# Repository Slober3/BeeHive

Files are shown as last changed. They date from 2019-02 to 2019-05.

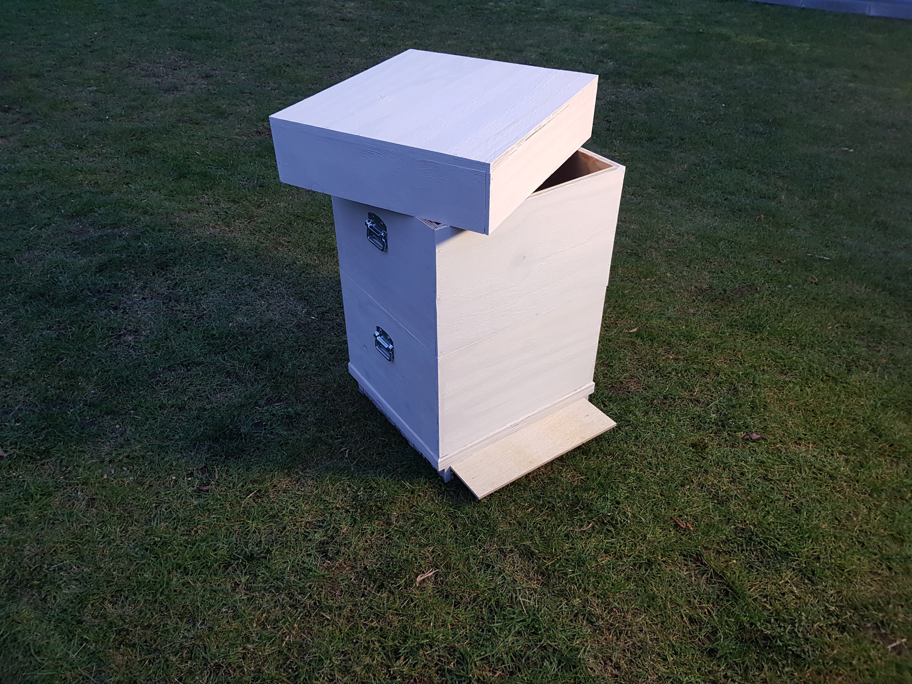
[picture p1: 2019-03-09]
20190309_183631.jpg

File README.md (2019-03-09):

# BeeHive
Beehive Prototype

Open source IOT beehive 

## What is it?
A simple lightweight packet for creating a functional DIY (IOT ready) beehive.

## How does it work?

BEEHIVE:

All the files are publicly available. With these resources you can create your own beehive for the fraction of the cost!

## Is this for anyone?
It's a pre-release and still in the early alpha stage.

## IOT
We are still in the design fase for the hive.
I'ts going to run  through the MQTT protocol and Node-RED

## Contributors
We are still searching brainstormers, users who would like to help and guys who would love to dive into this awesome project.
Manny thanks to the contributers that already are cotributing to this project.

## Contact

1) Email: beehive@7ol.eu

## License
This projects is Licensed under the CC-BY-NC-SA-4.0 license

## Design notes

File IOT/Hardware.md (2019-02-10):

# Controller
The IOT beehive will run on a ESP32 microcontroller platform

## What is it?
ESP32 is a series of low-cost, low-power system on a chip microcontrollers with integrated Wi-Fi and dual-mode Bluetooth. 
The ESP32 series employs a Tensilica Xtensa LX6 microprocessor in both dual-core and single-core variations and includes in-built antenna switches, RF balun, power amplifier, low-noise receive amplifier, filters, and power-management modules.
Source: https://en.wikipedia.org/wiki/ESP32

## Sensor array

We're using a variety of diffrent sensors they include but are not limeted to

1) Barrometric sensor

2) Temperature senor

3) Humidity sensor

4) Volatile Organic Compounds (VOC) sensor

These sensors will be measured by an BME680 Sensor 

## Is this for anyone?
Currently it'll require a moderate knowledge of programming and elektronics.

## API

The API is working! It's still running on fossil fuels and is currently beining updated to run on solar!
```
Formatted JSON Data
[  
   {  
      "id":"1238",
      "temp":"22",
      "gas":"*****",
      "lv":"22",
      "hum":"33"
   }
]
```

## Contributors
We are still searching brainstormers, users who would like to help and guys who would love to dive into this awesome project.
Manny thanks to the contributers that already are cotributing to this project.

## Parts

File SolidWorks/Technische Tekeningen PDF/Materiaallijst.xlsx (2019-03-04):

ITEM NO. | PART NUMBER | DESCRIPTION | QTY.
1 | Bodemplaat met opening voor raster 18mm | Afm. (LBH) 495x457x18 | 1
2 | Balkje lang voor verhoging bodemplaat met raster | Afm. (LBH) 495x12x18 | 1
3 | Balkje kort voor verhoging bodemplaat met raster | Afm. (LBH) 445x12x18 | 2
4 | Bovenplaat van het deksel 18mm dikte | Afm. (LBH) 535x490x18 | 1
5 | Langste zijde dakje buitenkant 18mm dikte | Afm. (LBH) 535x120x18. | 2
6 | Korte zijde dakje buitenkant 18mm dikte | Afm. (LBH) 490x120x18 | 2
7 | Langste zijde dakje binnenkant 18mm dikte | Afm. (LBH) 499x70x18 | 2
8 | Korte zijde dakje binnenkant 18mm dikte | Afm. (LBH) 436x70x18 | 2
9 | Bovenplaat met gat (plexi) | Afm. (LBH) 490x445x(xx) | 1
10 | Lange buitenzijde 18mm dikte | Afm. (LBH) 490x300x18 | 2
11 | Korte buitenzijde 18mm dikte | Afm. (LBH) 427x300x18 | 2
12 | Balkjes 12mm dikte | Afm. (LBH) 454x12x12 | 4
13 | Lange binnenzijde 12mm dikte | Afm. (LBH) 454x277x12 | 2
14 | Binnevlieggat 12mm dikte | Afm. (LBH) 495x25x12 | 1
15 | 30 voetstuk bijenkast bijenkasthouder links rechts 30mm dikte (2) | Afm. (LBH) 457x60x30 | 1
16 | 30 voetstuk bijenkast bijenkasthouder links rechts 30mm dikte | Afm. (LBH) 457x60x30 | 1
17 | luchtplaat afdichting bodem | Afm. (LBH) 455x445x8 | 1
18 | stopplankjes poten | Afm. (LBH) 455x17x12 | 2

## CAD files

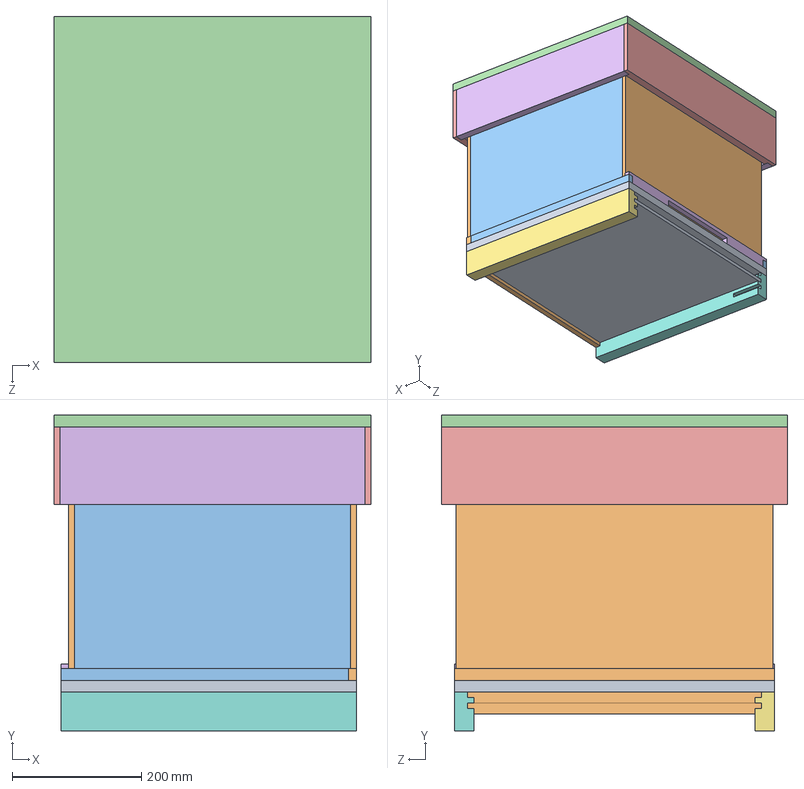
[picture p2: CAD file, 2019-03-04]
SolidWorks/Solidworks assemblys/Bijenkast.SLDASM
490.0 x 488.0 x 535.0 mm
Bodemplaat met opening voor raster 18mm
Balkje lang voor verhoging bodemplaat met raster
Balkje kort voor verhoging bodemplaat met raster x 2
19 Bovenplaat van het deksel 19mm dikte
19 langste zijde dakje buitenkant 19mm dikte x 2
19 korte zijde dakje buitenkant 19mm dikte x 2
19 langste zijde dakje binnenkant 19mm dikte x 2
19 korte zijde dakje binnenkant 19mm dikte x 2
Bovenplaat met gat (plexi)
19 lange buitenzijde 19mm dikte x 2
19 Korte buitenzijde 19mm dikte x 2
12 balkjes 12mm dikte x 4
12 lange binnenzijde 12mm dikte x 2
12 binnevlieggat 12mm dikte
30 voetstuk bijenkast bijenkasthouder links rechts 30mm dikte (2)
30 voetstuk bijenkast bijenkasthouder links rechts 30mm dikte
luchtplaat afdichting bodem
stopplankjes poten x 2

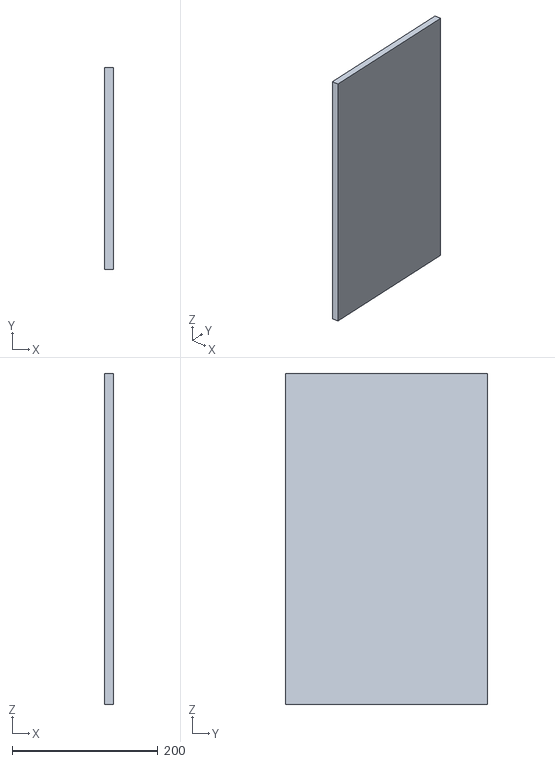
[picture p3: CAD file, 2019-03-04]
STL/Bijenkast - Kast +Dak + Raster bodem + vlieggat Assembly-2 Kast +Dak + Raster bodem Assembly-1 Kast +Dak Assembly-2 Kast Assembly-2 12 lange binnenzijde 12mm dikte-6.STL
12.0 x 277.0 x 454.0

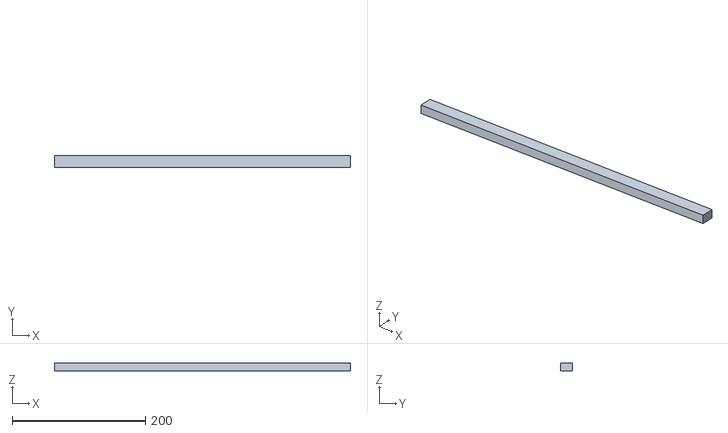
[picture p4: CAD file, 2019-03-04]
STL/Bijenkast - Kast +Dak + Raster bodem + vlieggat Assembly-2 Kast +Dak + Raster bodem Assembly-1 Bodem met raster Assembly-1 Balkje kort voor verhoging bodemplaat met raster-4.STL
445.0 x 18.0 x 12.0

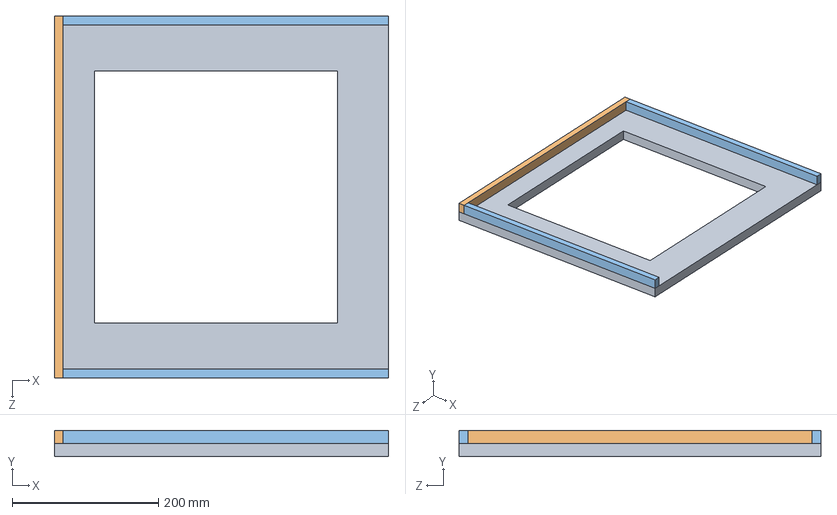
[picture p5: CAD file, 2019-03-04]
SolidWorks/Solidworks assemblys/Bodem met raster Assembly.SLDASM
457.0 x 36.0 x 495.0 mm
Bodemplaat met opening voor raster 18mm
Balkje lang voor verhoging bodemplaat met raster
Balkje kort voor verhoging bodemplaat met raster x 2

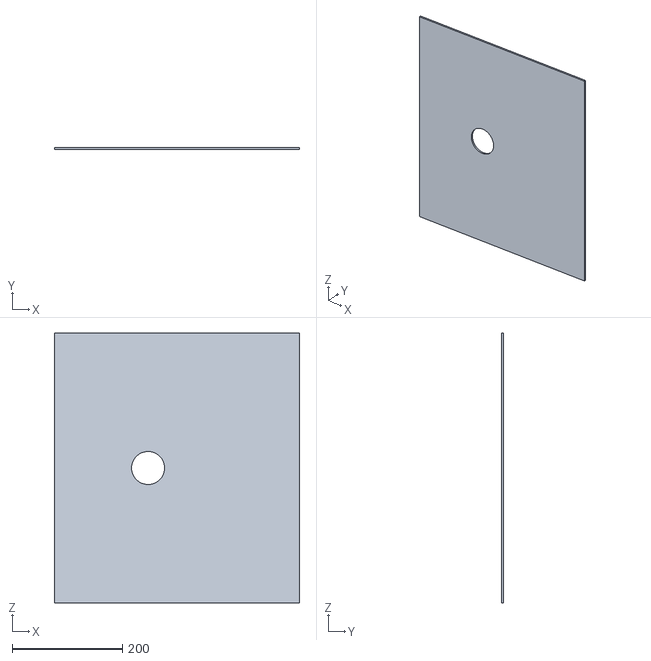
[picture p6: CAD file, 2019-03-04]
STL/Bijenkast - Kast +Dak + Raster bodem + vlieggat Assembly-2 Kast +Dak + Raster bodem Assembly-1 Kast +Dak Assembly-2 Bovenplaat met gat (plexi)-2.STL
445.0 x 4.00 x 490.0

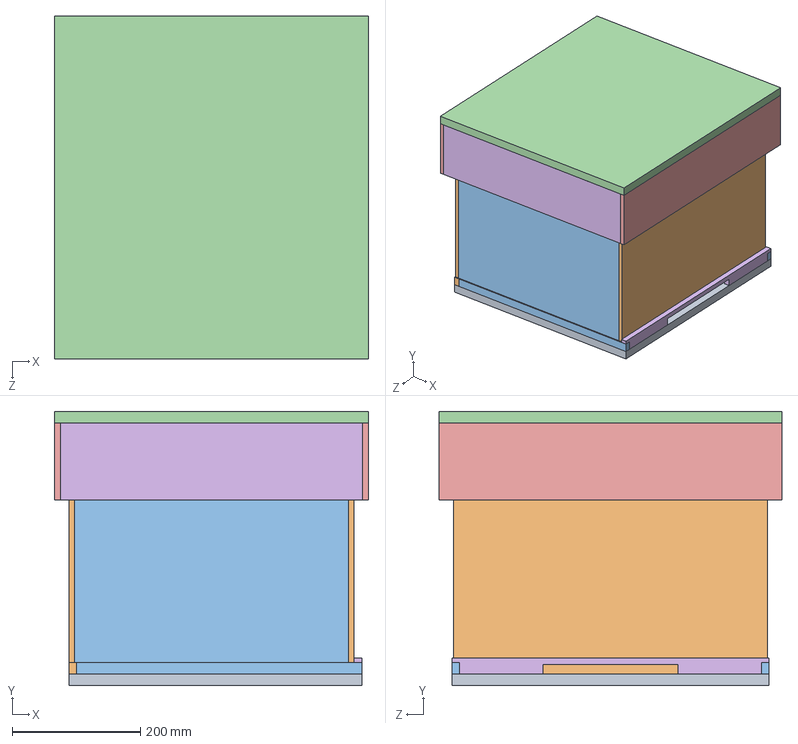
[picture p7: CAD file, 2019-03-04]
SolidWorks/Solidworks assemblys/Kast +Dak + Raster bodem + vlieggat Assembly.SLDASM
490.0 x 428.0 x 535.0 mm
Bodemplaat met opening voor raster 18mm
Balkje lang voor verhoging bodemplaat met raster
Balkje kort voor verhoging bodemplaat met raster x 2
19 Bovenplaat van het deksel 19mm dikte
19 langste zijde dakje buitenkant 19mm dikte x 2
19 korte zijde dakje buitenkant 19mm dikte x 2
19 langste zijde dakje binnenkant 19mm dikte x 2
19 korte zijde dakje binnenkant 19mm dikte x 2
Bovenplaat met gat (plexi)
19 lange buitenzijde 19mm dikte x 2
19 Korte buitenzijde 19mm dikte x 2
12 balkjes 12mm dikte x 4
12 lange binnenzijde 12mm dikte x 2
12 binnevlieggat 12mm dikte

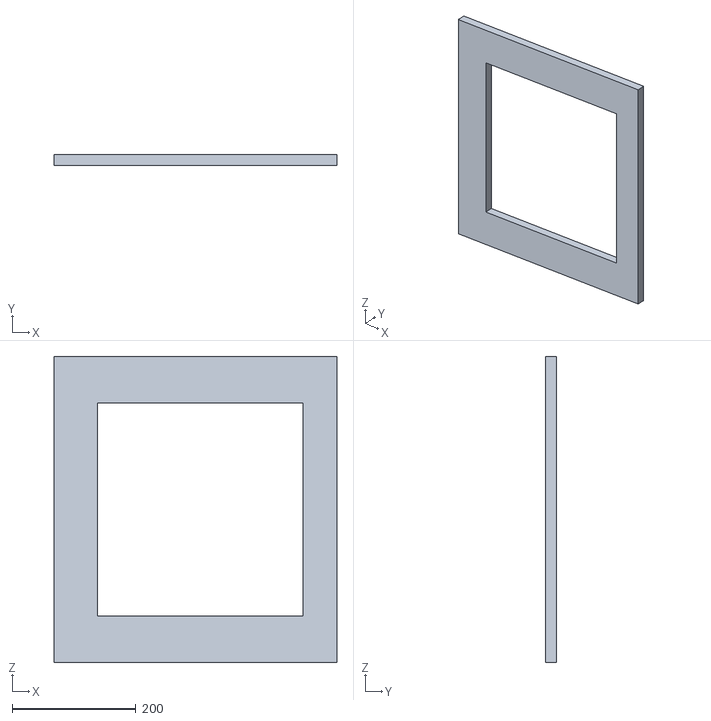
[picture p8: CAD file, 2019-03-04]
STL/Bijenkast - Kast +Dak + Raster bodem + vlieggat Assembly-2 Kast +Dak + Raster bodem Assembly-1 Bodem met raster Assembly-1 Bodemplaat met opening voor raster 18mm-1.STL
457.0 x 18.0 x 495.0

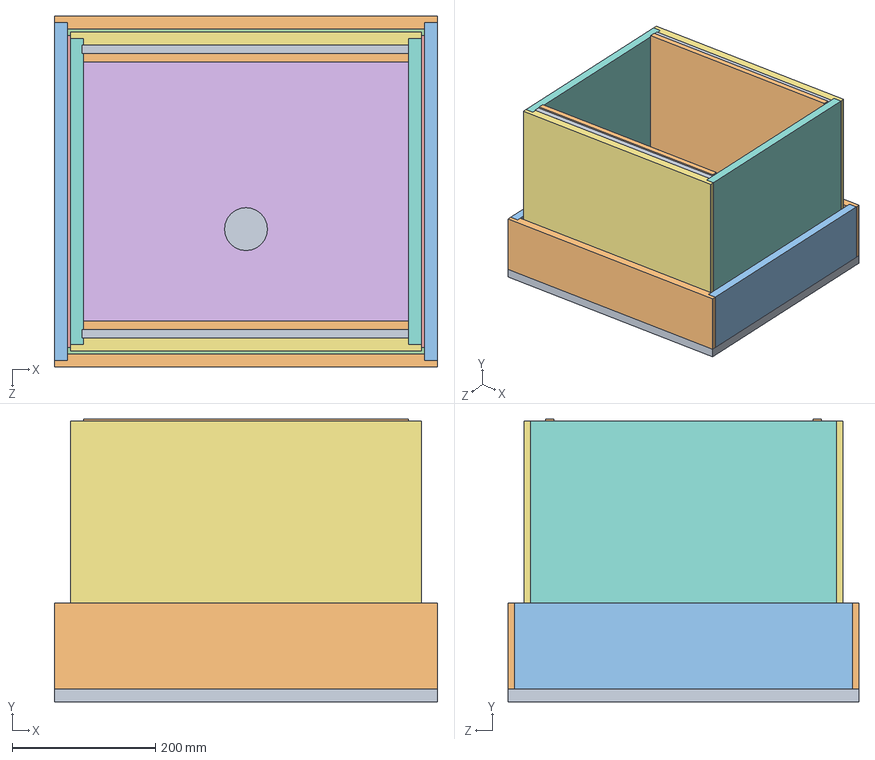
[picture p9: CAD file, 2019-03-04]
SolidWorks/Solidworks assemblys/Kast +Dak Assembly.SLDASM
535.0 x 395.0 x 490.0 mm
19 Bovenplaat van het deksel 19mm dikte
19 langste zijde dakje buitenkant 19mm dikte x 2
19 korte zijde dakje buitenkant 19mm dikte x 2
19 langste zijde dakje binnenkant 19mm dikte x 2
19 korte zijde dakje binnenkant 19mm dikte x 2
Bovenplaat met gat (plexi)
19 lange buitenzijde 19mm dikte x 2
19 Korte buitenzijde 19mm dikte x 2
12 balkjes 12mm dikte x 4
12 lange binnenzijde 12mm dikte x 2

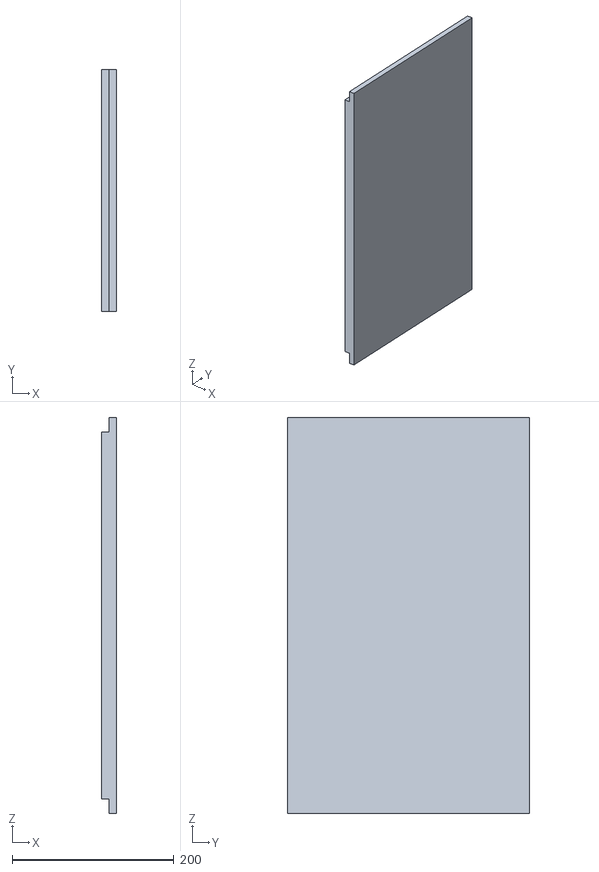
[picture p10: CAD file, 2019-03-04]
STL/Bijenkast - Kast +Dak + Raster bodem + vlieggat Assembly-2 Kast +Dak + Raster bodem Assembly-1 Kast +Dak Assembly-2 Kast Assembly-2 19 lange buitenzijde 19mm dikte-3.STL
18.0 x 300.0 x 490.0

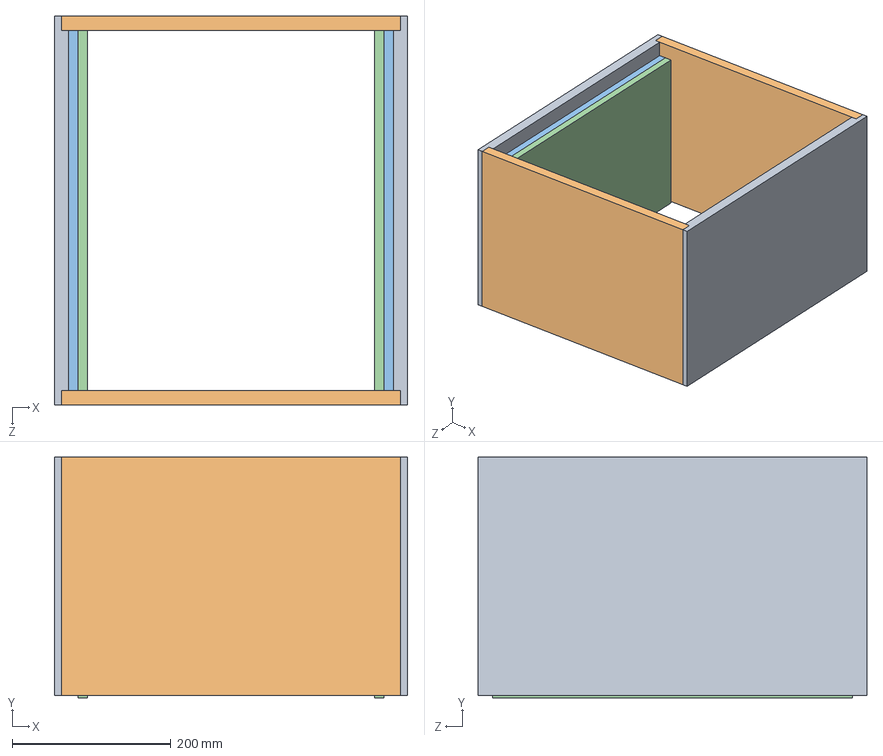
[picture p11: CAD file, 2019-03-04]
SolidWorks/Solidworks assemblys/Kast Assembly.SLDASM
445.0 x 303.0 x 490.0 mm
19 lange buitenzijde 19mm dikte x 2
19 Korte buitenzijde 19mm dikte x 2
12 balkjes 12mm dikte x 4
12 lange binnenzijde 12mm dikte x 2

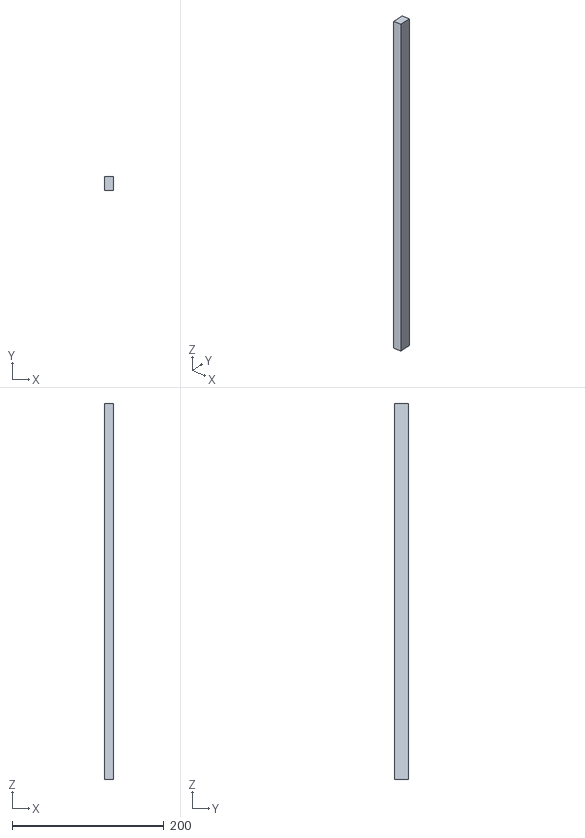
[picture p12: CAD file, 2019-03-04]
STL/Bijenkast - Kast +Dak + Raster bodem + vlieggat Assembly-2 Kast +Dak + Raster bodem Assembly-1 Bodem met raster Assembly-1 Balkje lang voor verhoging bodemplaat met raster-3.STL
12.0 x 18.0 x 495.0

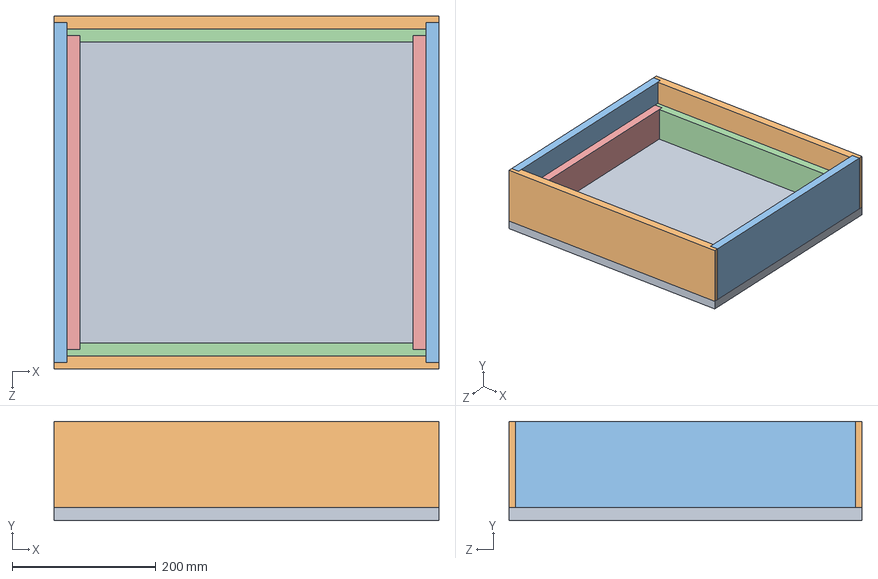
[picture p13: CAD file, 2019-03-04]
SolidWorks/Solidworks assemblys/Dakje Assembly.SLDASM
535.0 x 138.0 x 490.0 mm
19 Bovenplaat van het deksel 19mm dikte
19 langste zijde dakje buitenkant 19mm dikte x 2
19 korte zijde dakje buitenkant 19mm dikte x 2
19 langste zijde dakje binnenkant 19mm dikte x 2
19 korte zijde dakje binnenkant 19mm dikte x 2

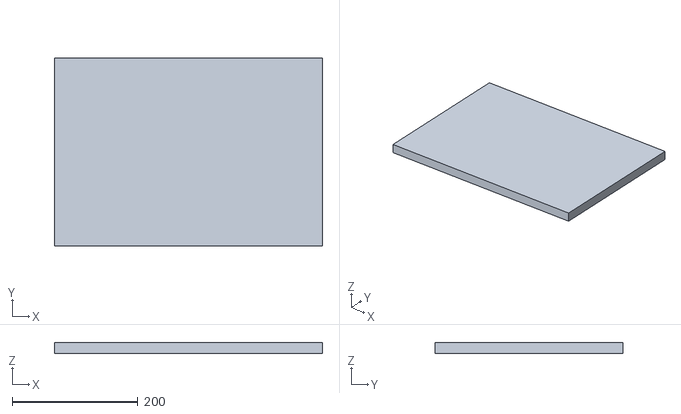
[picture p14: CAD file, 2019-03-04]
STL/Bijenkast - Kast +Dak + Raster bodem + vlieggat Assembly-2 Kast +Dak + Raster bodem Assembly-1 Kast +Dak Assembly-2 Kast Assembly-2 19 Korte buitenzijde 19mm dikte-3.STL
427.0 x 300.0 x 18.0

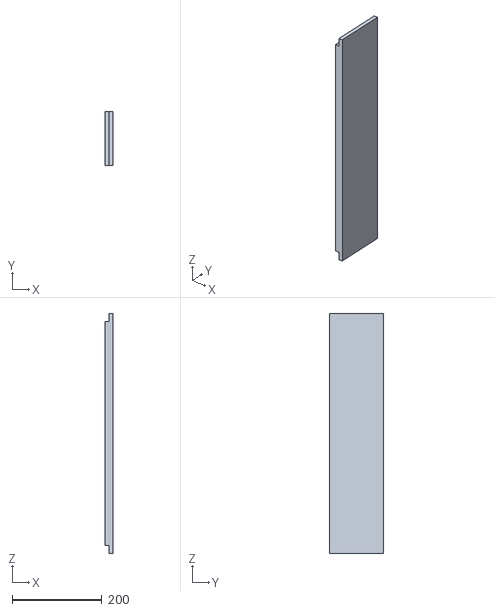
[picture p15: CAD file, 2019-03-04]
STL/Bijenkast - Kast +Dak + Raster bodem + vlieggat Assembly-2 Kast +Dak + Raster bodem Assembly-1 Kast +Dak Assembly-2 Dakje Assembly-1 19 langste zijde dakje buitenkant 19mm dikte-3.STL
18.0 x 120.0 x 535.0

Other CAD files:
SolidWorks/Solidworks assemblys/Kast +Dak + Raster bodem + vlieggat + poten Assembly.SLDASM
SolidWorks/Solidworks assemblys/Kast +Dak + Raster bodem Assembly.SLDASM
STL/Bijenkast - Kast +Dak + Raster bodem + vlieggat Assembly-2 Kast +Dak + Raster bodem Assembly-1 Kast +Dak Assembly-2 Kast Assembly-2 12 lange binnenzijde 12mm dikte-5.STL
STL/Bijenkast - Kast +Dak + Raster bodem + vlieggat Assembly-2 Kast +Dak + Raster bodem Assembly-1 Kast +Dak Assembly-2 Dakje Assembly-1 19 korte zijde dakje buitenkant 19mm dikte-3.STL
STL/Bijenkast - 30 voetstuk bijenkast bijenkasthouder links rechts 30mm dikte (2)-2.STL
STL/Bijenkast - 30 voetstuk bijenkast bijenkasthouder links rechts 30mm dikte-2.STL
STL/Bijenkast - Kast +Dak + Raster bodem + vlieggat Assembly-2 12 binnevlieggat 12mm dikte-1.STL
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

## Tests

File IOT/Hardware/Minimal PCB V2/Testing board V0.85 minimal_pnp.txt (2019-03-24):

*Pick And Place List
*Company=
*Author=
*eMail=
*
*Project=Testing board V0.85 minimal
*Date=13:51:05
*CreatedBy=Fritzing 0.9.3b.04.19.5c895d327c44a3114e5fcc9d8260daf0cbb52806
*
*
*Coordinates in mm, always center of component
*Origin 0/0=Lower left corner of PCB
*Rotation in degree (0-360, math. pos.)
*
*No;Value;Package;X;Y;Rotation;Side;Name
1;;molex-1x6-ra;45.3283;-15.377;0;Bottom;JP3
2;;;30.3478;-32.3251;0;Bottom;Onderdeel2
3;;;89.7783;-88.2051;0;Bottom;Hole6
4;;THT;17.7413;-11.4972;-90;Bottom;J8
5;;molex-1x6-ra;35.1683;-33.157;0;Bottom;JP1
6;;battery-18650-kit;43.0123;-57.6766;180;Bottom;BAT2
7;;THT;89.2703;-25.6222;0;Bottom;J11
8;;molex-1x6-ra;35.1683;-30.617;0;Bottom;JP2
9;;THT;89.2703;-15.4622;0;Bottom;J10
10;;battery-18650-kit;43.0123;-80.5366;180;Bottom;BAT1
11;;THT;89.2703;-5.30219;0;Bottom;J9
12;;;69.43;-10.6637;180;Bottom;Onderdeel3
13;;;64.3783;-31.6901;180;Bottom;Onderdeel1
14;;;5.95826;-4.38515;0;Bottom;Hole5

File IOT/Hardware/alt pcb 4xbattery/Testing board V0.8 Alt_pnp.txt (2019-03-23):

*Pick And Place List
*Company=
*Author=
*eMail=
*
*Project=Testing board V0.8 Alt
*Date=20:23:50
*CreatedBy=Fritzing 0.9.3b.04.19.5c895d327c44a3114e5fcc9d8260daf0cbb52806
*
*
*Coordinates in mm, always center of component
*Origin 0/0=Lower left corner of PCB
*Rotation in degree (0-360, math. pos.)
*
*No;Value;Package;X;Y;Rotation;Side;Name
1;;THT;28.6901;-62.2553;0;Bottom;J13
2;;;13.9581;-106.733;0;Bottom;Onderdeel1
3;;;21.5781;-40.0584;0;Bottom;Hole5
4;;battery-18650-kit;78.1647;-65.5234;0;Bottom;BAT3
5;;;115.558;-7.03843;0;Bottom;Hole6
6;;THT;28.6901;-92.7354;0;Bottom;J7
7;;battery-18650-kit;78.1647;-106.164;0;Bottom;BAT1
8;;battery-18650-kit;78.1647;-85.8435;0;Bottom;BAT2
9;;;13.9581;-111.178;0;Bottom;Hole4
10;;battery-18650-kit;78.1647;-45.2034;0;Bottom;BAT4
11;;THT;5.83015;-36.8553;0;Bottom;J5
12;;THT;28.6901;-82.5753;0;Bottom;J8
13;;2x10_lock;22.9751;-18.4684;90;Bottom;JP1
14;;;6.33813;-7.03843;0;Bottom;Hole1
15;;THT;5.83015;-47.0153;0;Bottom;J6
16;;;73.3884;-17.1984;0;Bottom;Onderdeel2
17;;THT;5.83015;-26.6953;0;Bottom;J20
18;;THT;28.6901;-72.4153;0;Bottom;J9
19;;;24.1464;-41.2573;0;Bottom;Onderdeel3

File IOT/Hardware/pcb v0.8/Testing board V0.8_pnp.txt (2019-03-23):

*Pick And Place List
*Company=
*Author=
*eMail=
*
*Project=Testing board V0.8
*Date=20:27:05
*CreatedBy=Fritzing 0.9.3b.04.19.5c895d327c44a3114e5fcc9d8260daf0cbb52806
*
*
*Coordinates in mm, always center of component
*Origin 0/0=Lower left corner of PCB
*Rotation in degree (0-360, math. pos.)
*
*No;Value;Package;X;Y;Rotation;Side;Name
1;;;75.9284;-27.3584;0;Bottom;Onderdeel2
2;;;21.5781;-45.1384;0;Bottom;Hole5
3;;;6.33813;-7.03843;0;Bottom;Hole1
4;;THT;36.1552;-22.7865;90;Bottom;J25
5;;THT;15.9901;-29.2353;0;Bottom;J20
6;;THT;8.37015;-38.4355;0;Bottom;J5
7;;battery-18650-kit;76.4121;-85.8269;0;Bottom;BAT2
8;;THT;8.37015;-48.5955;0;Bottom;J6
9;;;26.6864;-43.7973;0;Bottom;Onderdeel3
10;;THT;28.6901;-82.5753;0;Bottom;J8
11;;;115.558;-7.03843;0;Bottom;Hole6
12;;;13.9581;-111.178;0;Bottom;Hole4
13;;THT;28.6901;-72.4153;0;Bottom;J9
14;;THT;36.1551;-15.1664;90;Bottom;J26
15;;THT;28.6901;-92.7354;0;Bottom;J7
16;;THT;33.6152;-63.4265;90;Bottom;J13
17;;THT;36.1552;-30.4065;90;Bottom;J24
18;;battery-18650-kit;76.4121;-65.5068;0;Bottom;BAT3
19;;;13.9581;-106.733;0;Bottom;Onderdeel1
20;;THT;8.37015;-79.0755;0;Bottom;J1
21;;battery-18650-kit;76.4121;-106.147;0;Bottom;BAT1
22;;THT;8.37015;-89.2354;0;Bottom;J2

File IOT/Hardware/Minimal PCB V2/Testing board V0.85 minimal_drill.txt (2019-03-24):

; NON-PLATED HOLES START AT T1
; THROUGH (PLATED) HOLES START AT T100
M48
INCH
T1C0.049194
T2C0.126000
T3C0.165354
T100C0.073000
T101C0.031496
T102C0.031833
T103C0.040000
T104C0.098425
T105C0.035433
T106C0.086614
T107C0.039370
%
T1
X022345Y002670
T2
X006073Y031727
X027970Y022728
X006073Y022728
X027970Y031727
T3
X035345Y034726
X002345Y001726
T100
X002655Y031732
X031345Y031726
X002655Y022733
X031345Y022726
T101
X002950Y014025
X002950Y011427
T102
X022345Y005670
X022345Y004670
X032470Y001642
X032470Y005642
X032470Y002642
X032470Y003642
X032470Y004642
X022345Y003670
X032470Y006642
T103
X006345Y004726
X017345Y004726
X014345Y010726
X015345Y011726
X013345Y011726
X035345Y010726
X013345Y010726
X018345Y004726
X016345Y011726
X011345Y010726
X012345Y011726
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

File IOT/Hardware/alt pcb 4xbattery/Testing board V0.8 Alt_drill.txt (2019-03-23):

; NON-PLATED HOLES START AT T1
; THROUGH (PLATED) HOLES START AT T100
M48
INCH
T1C0.126000
T2C0.049194
T3C0.165354
T100C0.031496
T101C0.040000
T102C0.086614
T103C0.039370
T104C0.035433
T105C0.073000
T106C0.031833
T107C0.098425
%
T1
X041810Y025776
X041810Y017776
X019912Y033776
X019912Y025776
X019912Y017776
X019912Y041776
X041810Y041776
X041810Y033776
T2
X014495Y017771
T3
X005495Y043771
X008495Y015771
X045495Y002770
X002495Y002770
T100
X037890Y005471
X037890Y008070
T101
X008495Y002770
X011495Y035771
X009495Y008771
X009495Y002770
X008495Y004770
X011495Y027771
X009495Y010771
X011495Y023771
X009595Y005770
X008595Y005770
X002495Y009771
X009595Y007770
X008495Y008771
X008595Y009771
X002495Y015148
X011495Y031771
X009495Y006770
X009595Y003770
X009595Y011771
X011495Y037149
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

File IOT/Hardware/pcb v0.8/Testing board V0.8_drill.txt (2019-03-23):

; NON-PLATED HOLES START AT T1
; THROUGH (PLATED) HOLES START AT T100
M48
INCH
T1C0.049194
T2C0.165354
T3C0.126000
T100C0.031496
T101C0.040000
T102C0.086614
T103C0.039370
T104C0.035433
T105C0.073000
T106C0.031833
T107C0.098425
%
T1
X015495Y018771
T2
X005495Y043771
X008495Y017771
X045495Y002770
X002495Y002770
T3
X041120Y041769
X019222Y041769
X041120Y033769
X019222Y025769
X041120Y025769
X019222Y033769
T100
X038890Y009471
X038890Y012070
T101
X014873Y011771
X011495Y035771
X011495Y027771
X013495Y005770
X003495Y018393
X013495Y011771
X013873Y024771
X003495Y015771
X003495Y031771
X003495Y014393
X003495Y019771
X006495Y012148
X011495Y031771
X006495Y010771
X014873Y005770
X003495Y034393
X011495Y037149
X013495Y008771
X003495Y030393
X003495Y035771
X011495Y033148
X014873Y008771
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

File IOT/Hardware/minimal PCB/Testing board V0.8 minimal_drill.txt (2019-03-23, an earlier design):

; NON-PLATED HOLES START AT T1
; THROUGH (PLATED) HOLES START AT T100
M48
INCH
T1C0.126000
T2C0.049194
T3C0.165354
T100C0.039370
T101C0.035433
T102C0.098425
T103C0.040000
T104C0.073000
T105C0.086614
T106C0.031496
T107C0.031833
%
T1
X027810Y028037
X005912Y019037
X005912Y028037
X027810Y019037
T2
X011370Y024963
T3
X031495Y001991
X002495Y001991
T100
X025495Y007991
X023495Y007991
X022495Y007991
X026495Y007991
X024495Y007991
X028495Y007991
X027495Y007991
T101
X011533Y013007
X004533Y005007
X015533Y005007
X012533Y013007
X014533Y005007
X010533Y005007
X007533Y005007
X002035Y010424
X006533Y005007
X011533Y005007
X012533Y005007
X016533Y013007
X008533Y005007
X018533Y005007
X017533Y005007
X014533Y013007
X007533Y013007
X013533Y005007
X009533Y013007
X015533Y013007
X017533Y013007
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

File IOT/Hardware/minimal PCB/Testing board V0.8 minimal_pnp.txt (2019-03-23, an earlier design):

*Pick And Place List
*Company=
*Author=
*eMail=
*
*Project=Testing board V0.8 minimal
*Date=21:03:38
*CreatedBy=Fritzing 0.9.3b.04.19.5c895d327c44a3114e5fcc9d8260daf0cbb52806
*
*
*Coordinates in mm, always center of component
*Origin 0/0=Lower left corner of PCB
*Rotation in degree (0-360, math. pos.)
*
*No;Value;Package;X;Y;Rotation;Side;Name
1;;THT;61.7101;-50.1154;0;Bottom;J11
2;;battery-18650-kit;42.6047;-71.1635;180;Bottom;BAT1
3;;;30.8251;-22.8782;0;Bottom;Onderdeel2
4;;;64.7581;-26.0134;0;Bottom;Onderdeel1
5;;;41.5524;-59.5268;0;Bottom;Onderdeel3
6;;molex-1x6-ra;35.5481;-26.2103;0;Bottom;JP1
7;;;79.9981;-5.05843;0;Bottom;Hole6
8;;THT;19.7011;-7.09053;-90;Bottom;J8
9;;THT;61.7101;-70.4354;0;Bottom;J9
10;;battery-18650-kit;42.6047;-48.3035;180;Bottom;BAT2
11;;THT;61.7101;-60.2754;0;Bottom;J10
12;;;6.33813;-5.05843;0;Bottom;Hole5

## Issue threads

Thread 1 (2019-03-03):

Dak bijenkast te groot

Slober3, 2019-03-03:
Verkeerde afmetingen van het dak.
Dit kan verholpen worden door de bovenplaat van het dak in te korten.
Dit zal verholpen worden in een toekomstige update.

Er zal tevens geopteerd worden om de zijpanelen van het dak te verzinken zoals ook gebeurd bij de buitenpanelen.

Slober3, 2019-03-03:
Update:

Dakje is gereviseerd probleem zou opgelost moeten zijn.

Closed 2019-03-03.

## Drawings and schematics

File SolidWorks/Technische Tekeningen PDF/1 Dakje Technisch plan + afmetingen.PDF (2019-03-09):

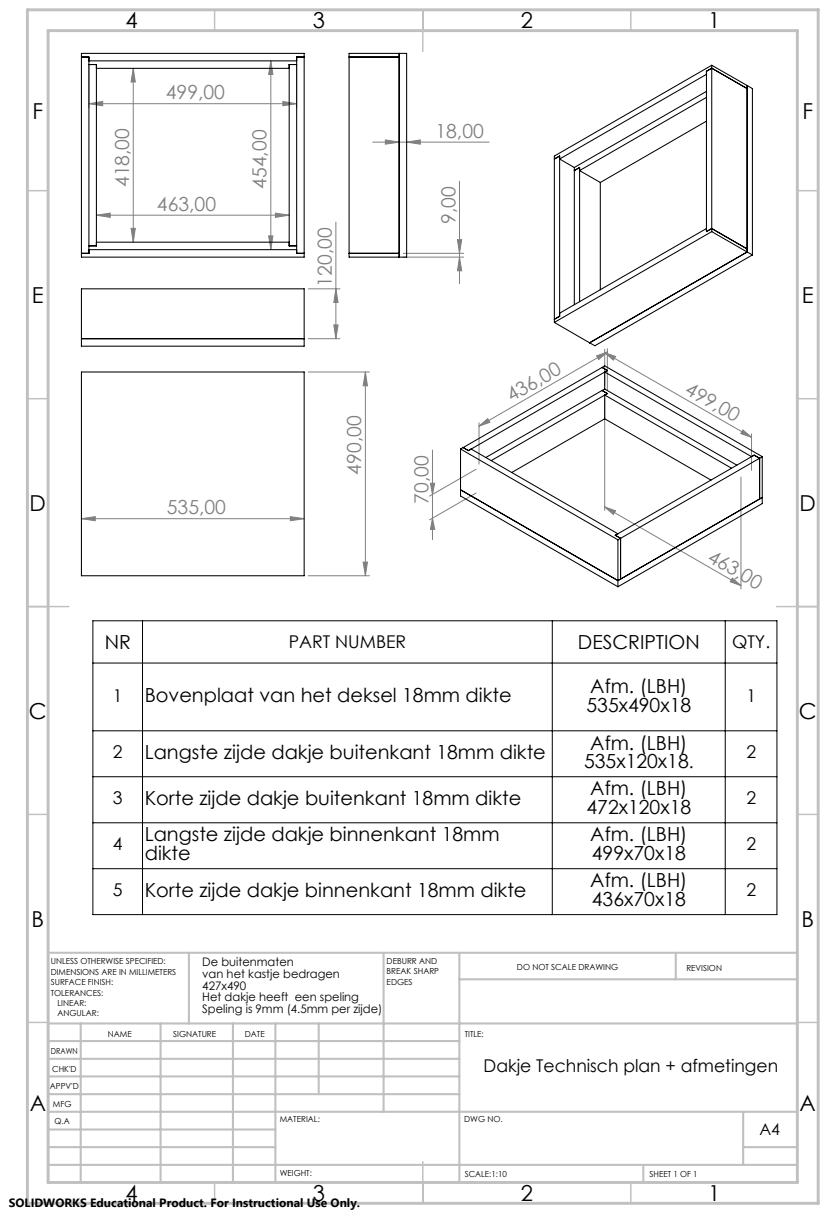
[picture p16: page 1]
DEBURR AND BREAK SHARP; DO NOT SCALE DRAWING; REVISION; SCALE:1:10; SHEET 1 OF 1

NR | PART NUMBER | DESCRIPTION | QTY.
1 | Bovenplaat van het deksel 18mm dikte | Afm. (LBH) 535x490x18 | 1

2 | Langste zijde dakje buitenkant 18mm dikte | Afm. (LBH) 535x120x18. | 2
3 | Korte zijde dakje buitenkant 18mm dikte | Afm. (LBH) 472x120x18 | 2
4 | Langste zijde dakje binnenkant 18mm dikte | Afm. (LBH) 499x70x18 | 2
5 | Korte zijde dakje binnenkant 18mm dikte | Afm. (LBH) 436x70x18 | 2

UNLESS OTHERWISE SPECIFIED:
DIMENSIONS ARE IN MILLIMETERS
SURFACE FINISH:
TOLERANCES:
LINEAR:
ANGULAR:

De buitenmaten
van het kastje bedragen
Het dakje heeft een speling
Speling is 9mm (4.5mm per zijde)

NAME | SIGNATURE | DATE | | | | TITLE: Dakje Technisch plan + afmetingen

DRAWN
CHK'D
APPV'D
MFG
Q.A | | | | MATERIAL: | DWG NO. | A4

SOLIDWORKS Educational Product. For Instructional Use Only.

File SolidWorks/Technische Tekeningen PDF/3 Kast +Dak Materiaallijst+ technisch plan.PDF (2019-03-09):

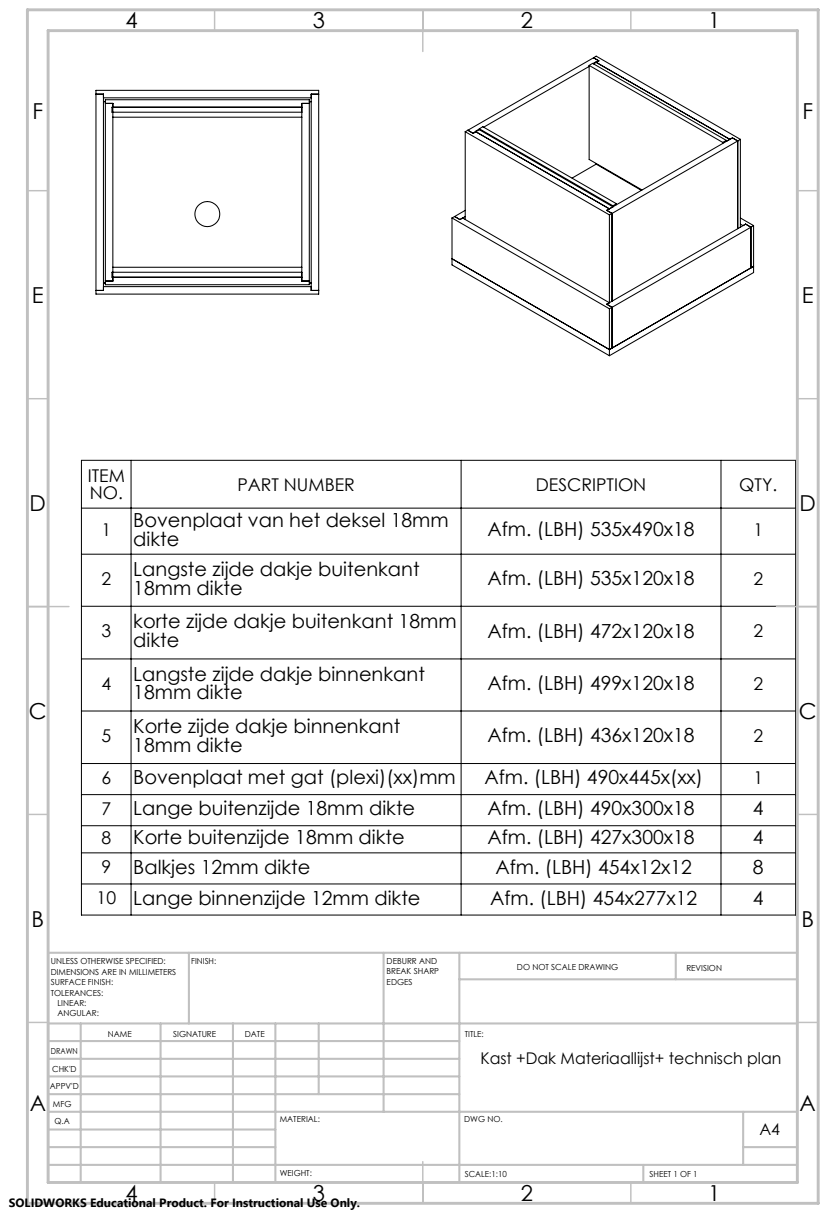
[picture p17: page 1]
FINISH:; DEBURR AND; BREAK SHARP; DO NOT SCALE DRAWING; REVISION; SCALE:1:10; SHEET 1 OF 1

ITEM NO. | PART NUMBER | DESCRIPTION | QTY.
1 | Bovenplaat van het deksel 18mm dikte | Afm. (LBH) 535x490x18 | 1
2 | Langste zijde dakje buitenkant 18mm dikte | Afm. (LBH) 535x120x18 | 2

3 | korte zijde dakje buitenkant 18mm dikte | Afm. (LBH) 472x120x18 | 2

4 | Langste zijde dakje binnenkant 18mm dikte | Afm. (LBH) 499x120x18 | 2

5 | Korte zijde dakje binnenkant 18mm dikte | Afm. (LBH) 436x120x18 | 2

6 | Bovenplaat met gat (plexi)(xx)mm | Afm. (LBH) 490x445x(xx) | 1
7 | Lange buitenzijde 18mm dikte | Afm. (LBH) 490x300x18 | 4
8 | Korte buitenzijde 18mm dikte | Afm. (LBH) 427x300x18 | 4
9 | Balkjes 12mm dikte | Afm. (LBH) 454x12x12 | 8
10 | Lange binnenzijde 12mm dikte | Afm. (LBH) 454x277x12 | 4

UNLESS OTHERWISE SPECIFIED:
DIMENSIONS ARE IN MILLIMETERS
SURFACE FINISH:
TOLERANCES:
LINEAR:
ANGULAR:

NAME | SIGNATURE | DATE | | | | TITLE: Kast +Dak Materiaallijst+ technisch plan

DRAWN
CHK'D
APPV'D
MFG
Q.A | | | | MATERIAL: | DWG NO. | A4

SOLIDWORKS Educational Product. For Instructional Use Only.

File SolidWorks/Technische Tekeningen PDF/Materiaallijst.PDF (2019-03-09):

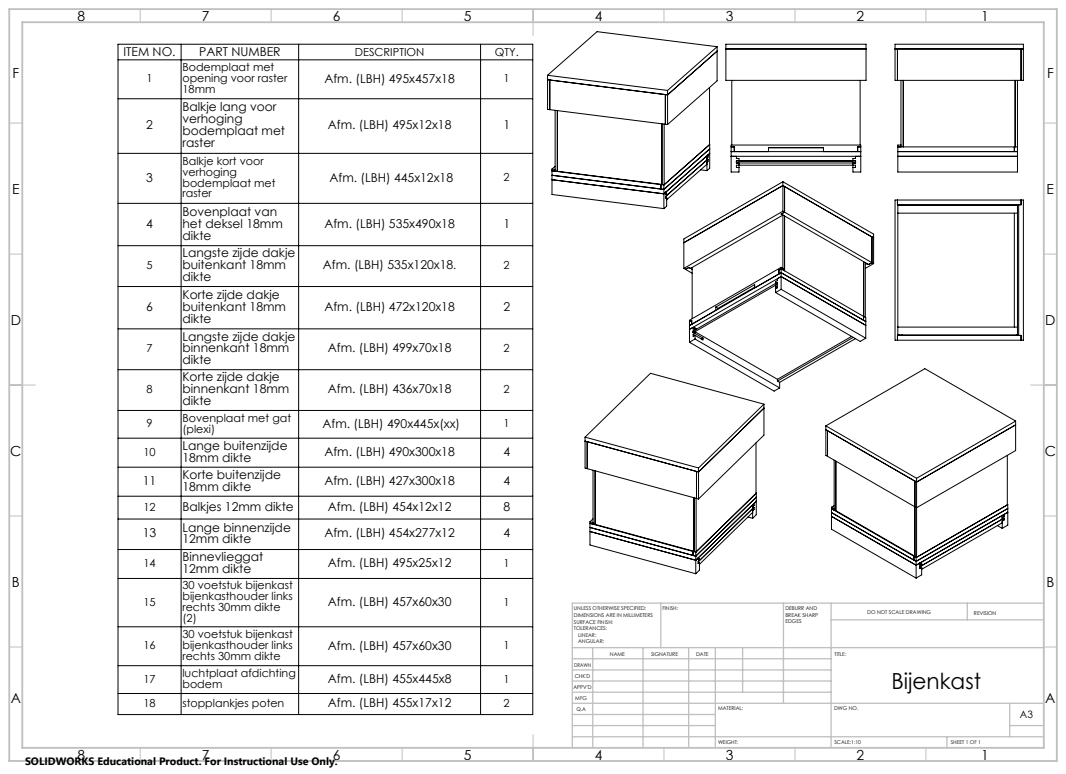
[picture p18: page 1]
stopplankjes poten; Afm. (LBH) 455x17x12; FINISH:; DEBURR AND; BREAK SHARP; DO NOT SCALE DRAWING; REVISION; SCALE:1:10; SHEET 1 OF 1

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

2 | Balkje lang voor verhoging bodemplaat met raster | Afm. (LBH) 495x12x18 | 1

3 | Balkje kort voor verhoging bodemplaat met raster | Afm. (LBH) 445x12x18 | 2

4 | Bovenplaat van het deksel 18mm dikte | Afm. (LBH) 535x490x18 | 1

5 | Langste zijde dakje buitenkant 18mm dikte | Afm. (LBH) 535x120x18. | 2

6 | Korte zijde dakje buitenkant 18mm dikte | Afm. (LBH) 472x120x18 | 2

7 | Langste zijde dakje binnenkant 18mm dikte | Afm. (LBH) 499x70x18 | 2

8 | Korte zijde dakje binnenkant 18mm dikte | Afm. (LBH) 436x70x18 | 2

9 | Bovenplaat met gat (plexi) | Afm. (LBH) 490x445x(xx) | 1
10 | Lange buitenzijde 18mm dikte | Afm. (LBH) 490x300x18 | 4
11 | Korte buitenzijde 18mm dikte | Afm. (LBH) 427x300x18 | 4

12 | Balkjes 12mm dikte | Afm. (LBH) 454x12x12 | 8
13 | Lange binnenzijde 12mm dikte | Afm. (LBH) 454x277x12 | 4
14 | Binnevlieggat 12mm dikte | Afm. (LBH) 495x25x12 | 1

15 | 30 voetstuk bijenkast bijenkasthouder links rechts 30mm dikte (2) | Afm. (LBH) 457x60x30 | 1

UNLESS OTHERWISE SPECIFIED:
DIMENSIONS ARE IN MILLIMETERS
SURFACE FINISH:
TOLERANCES:
LINEAR:
ANGULAR:

16 | 30 voetstuk bijenkast bijenkasthouder links rechts 30mm dikte | Afm. (LBH) 457x60x30 | 1

NAME | SIGNATURE | DATE | | | | TITLE: Bijenkast

DRAWN
CHK'D
APPV'D
MFG
Q.A | | | | MATERIAL: | DWG NO. | A3

17 | luchtplaat afdichting bodem | Afm. (LBH) 455x445x8 | 1

SOLIDWORKS Educational Product. For Instructional Use Only.

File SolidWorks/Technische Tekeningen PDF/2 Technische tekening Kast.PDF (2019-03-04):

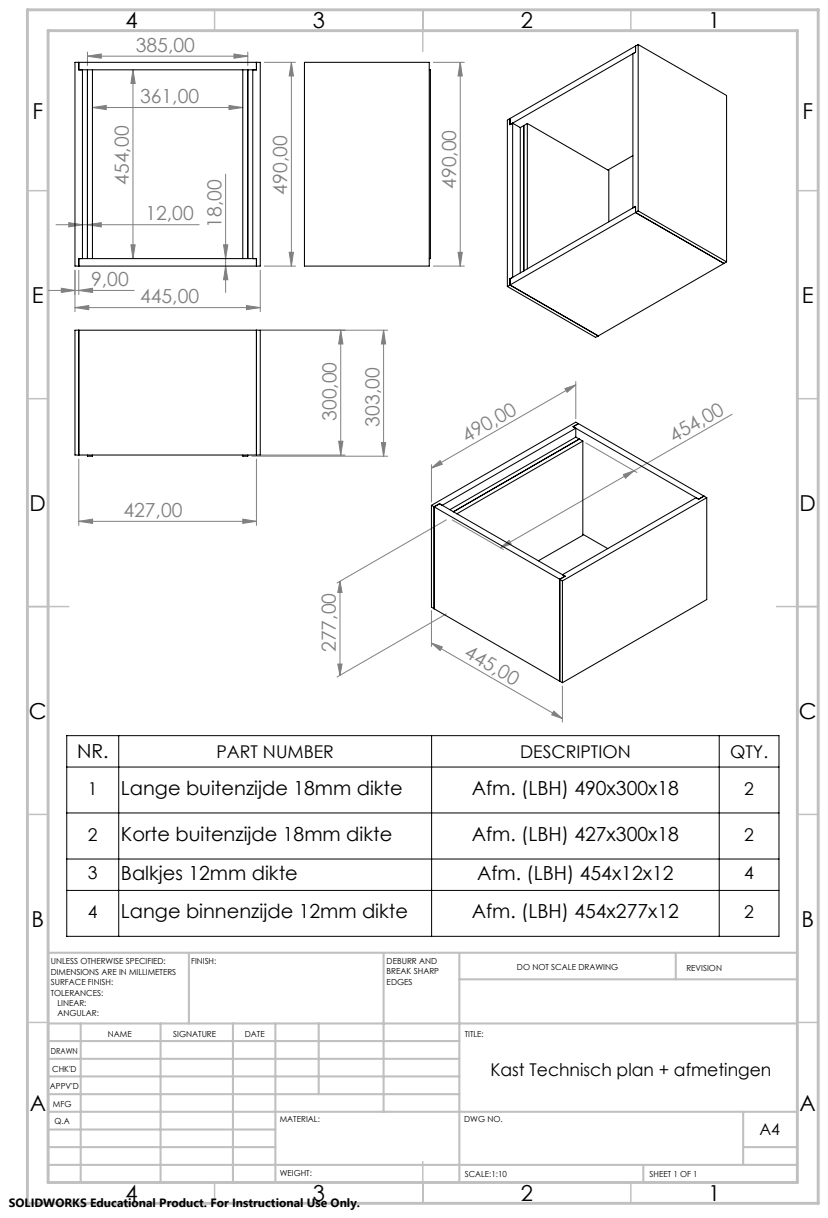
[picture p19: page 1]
Korte buitenzijde 18mm dikte; Afm. (LBH) 427x300x18; FINISH:; DEBURR AND; BREAK SHARP; DO NOT SCALE DRAWING; REVISION; SCALE:1:10; SHEET 1 OF 1

NR. | PART NUMBER | DESCRIPTION | QTY.
1 | Lange buitenzijde 18mm dikte | Afm. (LBH) 490x300x18 | 2

3 | Balkjes 12mm dikte | Afm. (LBH) 454x12x12 | 4
4 | Lange binnenzijde 12mm dikte | Afm. (LBH) 454x277x12 | 2

UNLESS OTHERWISE SPECIFIED:
DIMENSIONS ARE IN MILLIMETERS
SURFACE FINISH:
TOLERANCES:
LINEAR:
ANGULAR:

NAME | SIGNATURE | DATE | | | | TITLE: Kast Technisch plan + afmetingen

DRAWN
CHK'D
APPV'D
MFG
Q.A | | | | MATERIAL: | DWG NO. | A4

SOLIDWORKS Educational Product. For Instructional Use Only.

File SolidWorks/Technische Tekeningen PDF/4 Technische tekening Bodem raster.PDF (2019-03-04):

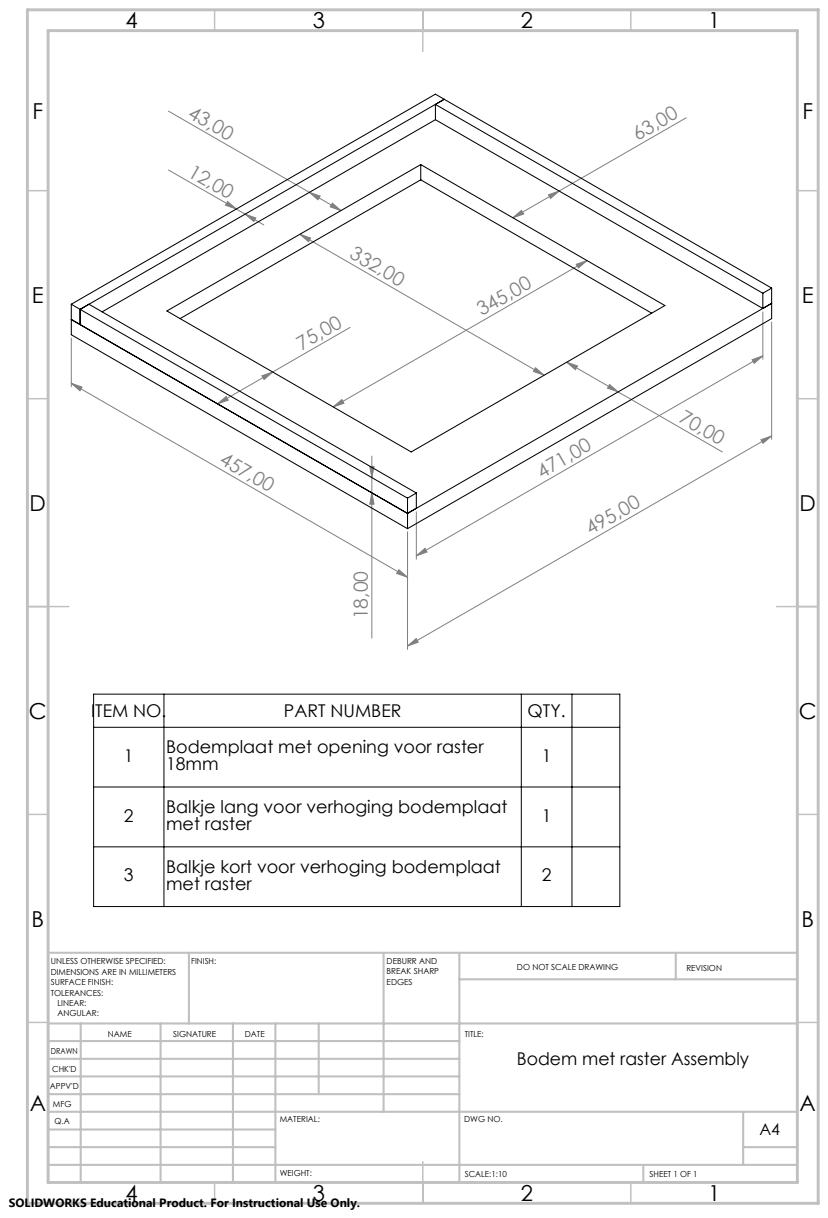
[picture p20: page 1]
ITEM NO.; PART NUMBER; QTY.; FINISH:; DEBURR AND; BREAK SHARP; DO NOT SCALE DRAWING; REVISION; SCALE:1:10; SHEET 1 OF 1

1 | Bodemplaat met opening voor raster 18mm | 1

2 | Balkje lang voor verhoging bodemplaat met raster | 1

3 | Balkje kort voor verhoging bodemplaat met raster | 2

UNLESS OTHERWISE SPECIFIED:
DIMENSIONS ARE IN MILLIMETERS
SURFACE FINISH:
TOLERANCES:
LINEAR:
ANGULAR:

NAME | SIGNATURE | DATE | | | | TITLE: Bodem met raster Assembly

DRAWN
CHK'D
APPV'D
MFG
Q.A | | | | MATERIAL: | DWG NO. | A4

SOLIDWORKS Educational Product. For Instructional Use Only.

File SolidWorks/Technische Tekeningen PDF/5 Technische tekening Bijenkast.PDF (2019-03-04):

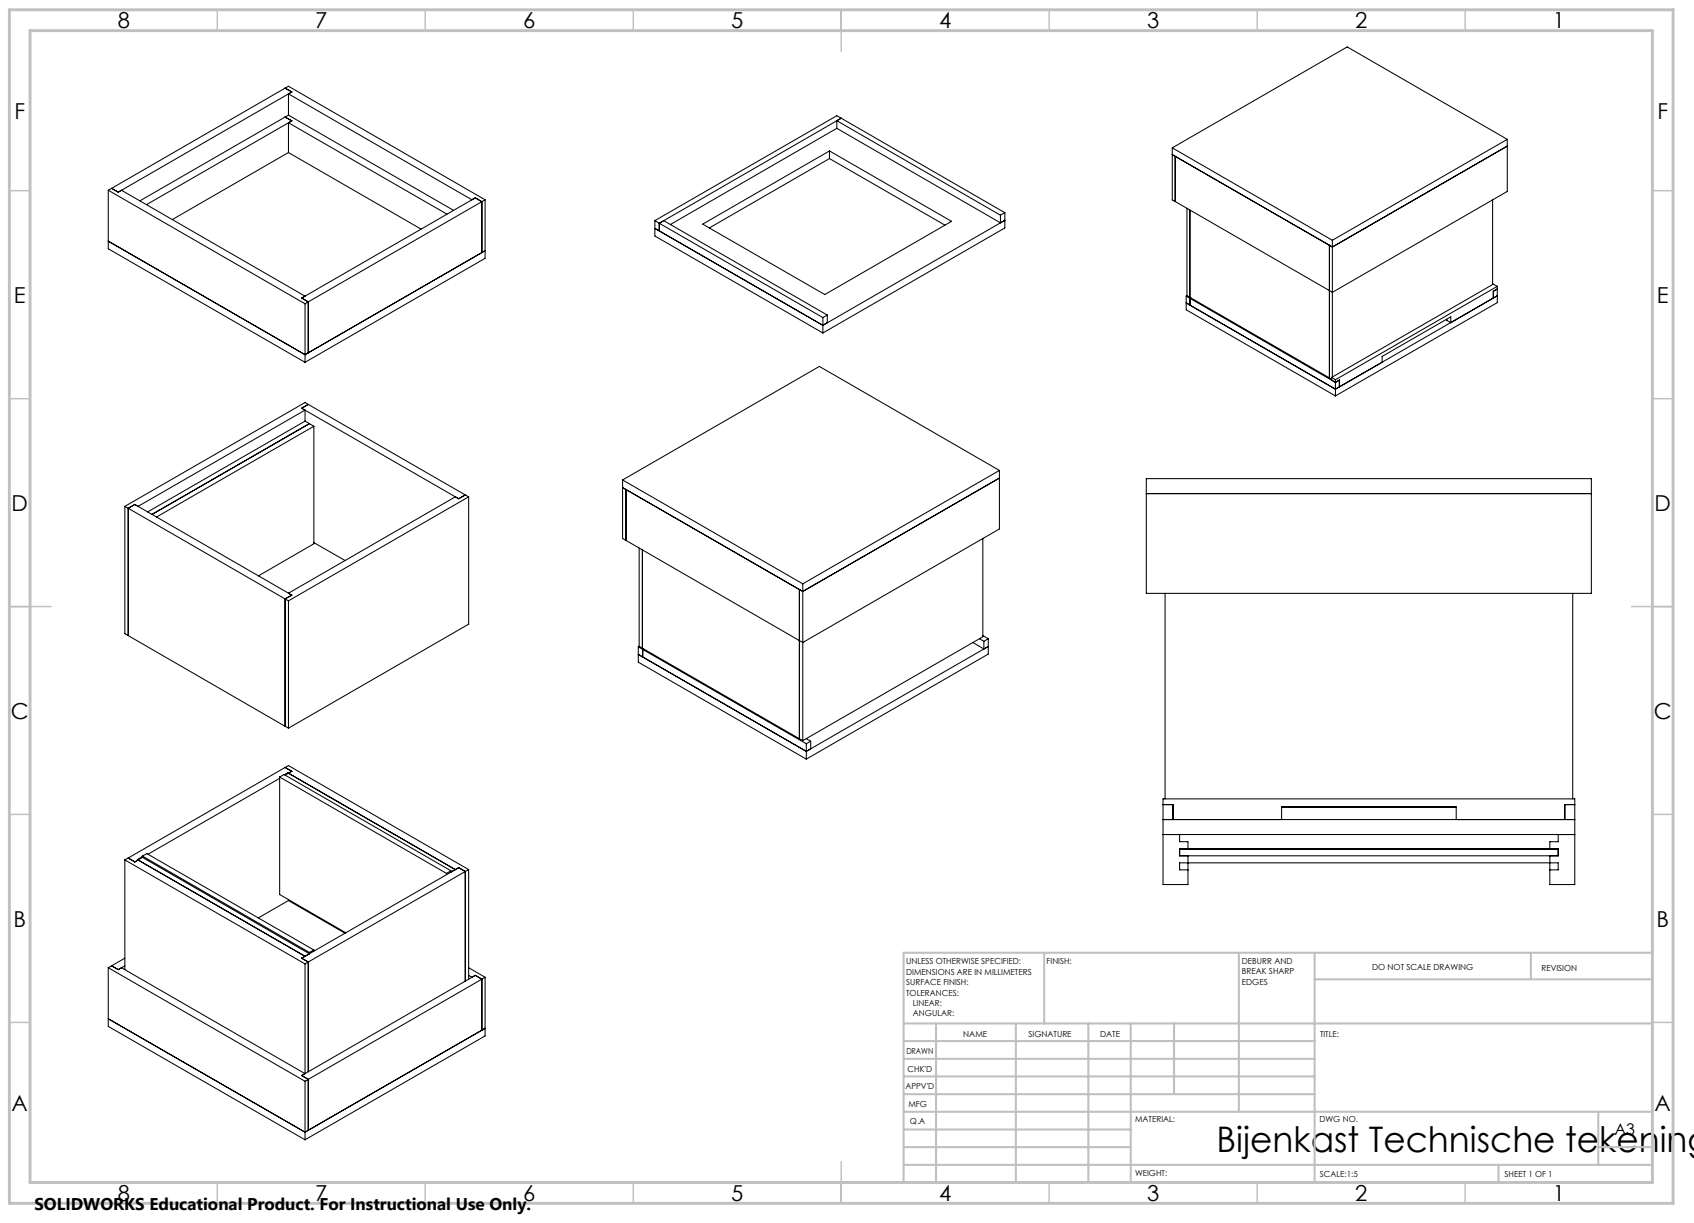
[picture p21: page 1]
FINISH:; DEBURR AND; BREAK SHARP; DO NOT SCALE DRAWING; REVISION; SCALE:1:5; SHEET 1 OF 1

UNLESS OTHERWISE SPECIFIED:
DIMENSIONS ARE IN MILLIMETERS
SURFACE FINISH:
TOLERANCES:
LINEAR:
ANGULAR:

NAME | SIGNATURE | DATE | | | | TITLE:

DRAWN
CHK'D
APPV'D
MFG
Q.A | | | | MATERIAL: | DWG NO. | A3

Bijenkast Technische tekening

SOLIDWORKS Educational Product. For Instructional Use Only.

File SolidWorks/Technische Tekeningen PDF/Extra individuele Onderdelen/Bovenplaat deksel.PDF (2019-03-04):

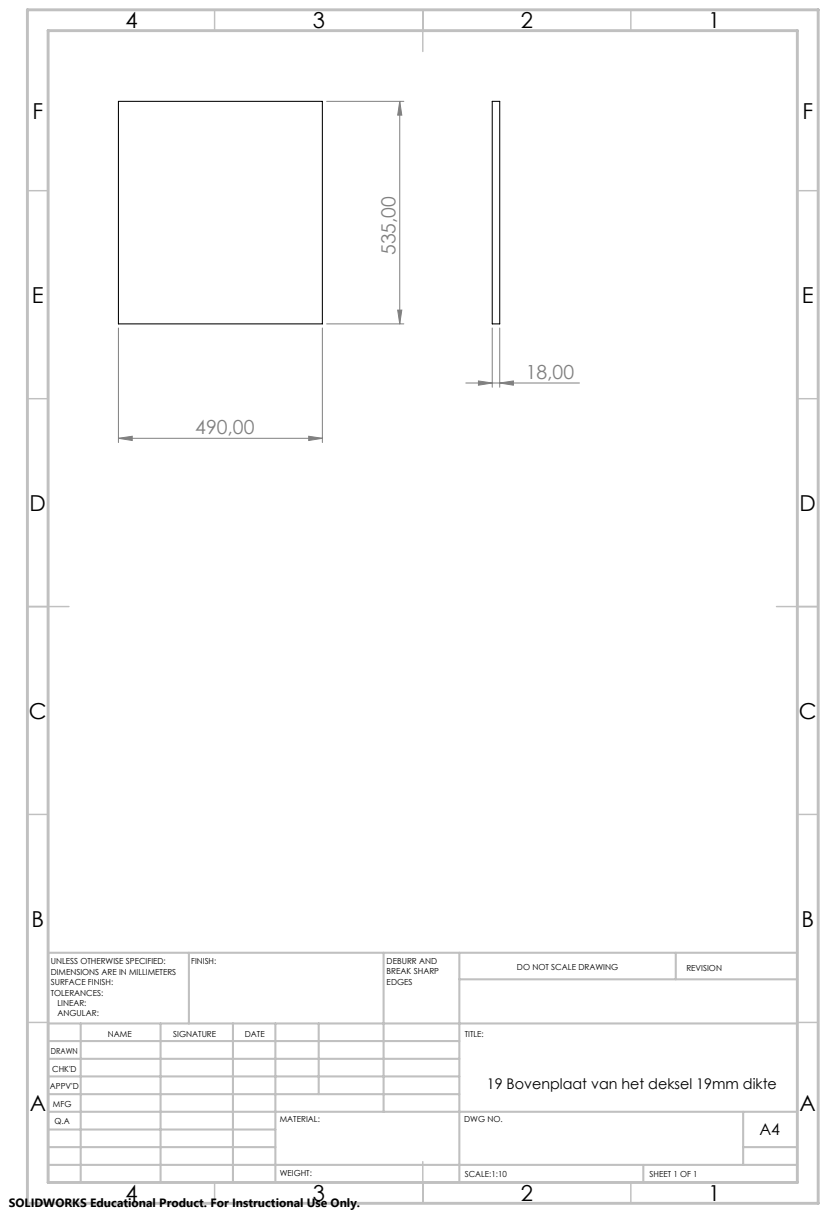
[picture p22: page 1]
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

UNLESS OTHERWISE SPECIFIED:
DIMENSIONS ARE IN MILLIMETERS
SURFACE FINISH:
TOLERANCES:
LINEAR:
ANGULAR:

NAME | SIGNATURE | DATE | | | | TITLE: 19 Bovenplaat van het deksel 19mm dikte

DRAWN
CHK'D
APPV'D
MFG
Q.A | | | | MATERIAL: | DWG NO. | A4

SOLIDWORKS Educational Product. For Instructional Use Only.

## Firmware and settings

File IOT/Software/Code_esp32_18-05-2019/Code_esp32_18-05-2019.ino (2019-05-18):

/***************************************************************************
Made by : Quinten Tom en Stijn
 ***************************************************************************/

#include <WiFi.h>                   //Lib voor wifi
#include "HX711.h"                  //Lib voor gewichtssensor
#include <PubSubClient.h>           //Lib voor MQTT
#include <Wire.h>                   //Lib voor I2C
#include <SPI.h>                    //Lib voor spi
#include <Adafruit_Sensor.h>        //Lib voor BME680
#include "Adafruit_BME680.h"        //Lib voor BME680

/*
 * Instellingen BME680 (pins) I2C
 */
#define BME_SCK 22
#define BME_MISO 12
#define BME_MOSI 11
#define BME_CS 23
#define SEALEVELPRESSURE_HPA (1013.25)
Adafruit_BME680 bme; // I2C

/*
 * Instellingen HX711 DOUTp = data CLKp = clock
 */
#define DOUTp  4
#define CLKp  5

/*
 * Kalibraties HX711
 */
float calibration_factor = -860;
float zero_factor;

/*
 * Deep sleep 
 */
#define uS_TO_S_FACTOR 1000000  /* Conversion factor for micro seconds to seconds */
#define TIME_TO_SLEEP  1200        /* Time ESP32 will go to sleep (in seconds) */
RTC_DATA_ATTR int bootCount = 0;

// Replace the next variables with your SSID/Password combination
const char* ssid = "derbaix";
const char* password = "epxw5djavcxNQjMucYPmuvXZJExQ4n";

// Add your MQTT Broker IP address, example:
const char* mqtt_server = "141.134.105.242";

//Tijdelijke string voor opslaan data MQTT
char tempString[8];

//HX711 initiatie
HX711 scale(DOUTp, CLKp);

//Initiatie WiFi+MQTT
WiFiClient espClient;
PubSubClient client(espClient);
long lastMsg = 0;
char msg[50];
int value = 0;
float tempvalweight = 0;



void setup() {
  /*
   * Initiatie serieel protocol
   */
  Serial.begin(9600);
  while (!Serial);
  Serial.println(F("BzZzZz array"));

/*
 * Initiatie BME680
 */
  if (!bme.begin(0x76)) {
    Serial.println("Could not find a valid BME680 sensor, check wiring!");
    while (1);
  }

  // Set up oversampling and filter initialization
  bme.setTemperatureOversampling(BME680_OS_8X);
  bme.setHumidityOversampling(BME680_OS_2X);
  bme.setPressureOversampling(BME680_OS_4X);
  bme.setIIRFilterSize(BME680_FILTER_SIZE_3);
  bme.setGasHeater(320, 150); // 320*C for 150 ms

/*
 * WiFi+MQTT
 */
  setup_wifi();
  client.setServer(mqtt_server, 1883);

  // setup weegschaal
 scale.set_scale(); 
 
//  for (int i = 0; i <= 3; i++) {
//    scale.tare(); //Reset the scale to 0
//    delay(300);  
// }

}

void setup_wifi() {
  delay(100);
  // We start by connecting to a WiFi network
  Serial.println();
  Serial.print("Connecting to ");
  Serial.println(ssid);

  WiFi.begin(ssid, password);

  while (WiFi.status() != WL_CONNECTED) {
    delay(500);
    Serial.print(".");
  }

  Serial.println("");
  Serial.println("WiFi connected");
  Serial.println("IP address: ");
  Serial.println(WiFi.localIP());
}


void reconnect() {
  // Loop until we're reconnected
  while (!client.connected()) {
    Serial.print("Attempting MQTT connection...");
    // Attempt to connect
    if (client.connect("ESP32Client")) {
      Serial.println("connected");
      // Subscribe
      client.subscribe("esp32/output");
    } else {
      Serial.print("failed, rc=");
      Serial.print(client.state());
      Serial.println(" try again in 5 seconds");
      // Wait 5 seconds before retrying
      delay(5000);
    }
  }
}

void loop() {

  if (!client.connected()) {
    reconnect();
  }
  client.loop();
  scale.set_scale(calibration_factor); //Adjust to this calibration factor

  
  if (! bme.performReading()) {
    Serial.println("Failed to perform reading :(");
    return;
  }

  /*
   * Publikatie MQTT data
   */
  dtostrf(bme.temperature, 1, 2, tempString);
  client.publish("bhive/1/temp", tempString);

  dtostrf(bme.pressure, 1, 2, tempString);
  client.publish("bhive/1/airp", tempString);

  
  dtostrf(bme.humidity, 1, 2, tempString);
  client.publish("bhive/1/hum", tempString);

  dtostrf(bme.readGas(), 1, 2, tempString);
  client.publish("bhive/1/airq", tempString);


  /*
  Serial.print(scale.get_units(), 3);
  tempvalweight = 0; 
  int vw;
    for (int i = 0; i <= 20; i++) {
      if (scale.get_units() < 200){
         tempvalweight = tempvalweight +scale.get_units();
        vw=vw+1;
        }
      
      delay(5);
    }
  
  tempvalweight = tempvalweight / vw;
  vw=0;
  */

  delay(1200);

tempvalweight = scale.get_units(16);
 if (tempvalweight > 200 || tempvalweight < -2){
     tempvalweight = scale.get_units(16);
     }
  

dtostrf(tempvalweight, 1, 2, tempString);
client.publish("bhive/1/weight", tempString);


  Serial.println();
  delay(100);

  /*
   * Start deep sleep
   */
 esp_sleep_enable_timer_wakeup(TIME_TO_SLEEP * uS_TO_S_FACTOR);
 esp_deep_sleep_start();

}

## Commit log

2019-02-09 Initial Commit
    Initial commit
    Toevoegen SolidWorks bestanden
    Toevoegen GCODE beestanden
    Toevoegen STL files
    [afdichtingsplaat bodem lucht.SLDPRT, balkjes.SLDPRT, balkjes.STL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]
2019-02-10 IOT POC added software examples
    Added software examples for the ESP32 microcontroller.
    Added a POC ESP32 program.
2019-02-26 Update bodemplaat
    Bodemplaat. 3mm verhoogd
    [bodemplaat bodem.SLDPRT]
2019-03-01 Hernoemen bestanden + toevoegen DXF 19mm
    Hernoemen bestanden + toevoegen DXF 19mm
    [10 extra stuk bodem onder 10mm dikte.SLDPRT, 12 balkjes 12mm dikte.SLDPRT, 12 binnevlieggat 12mm dikte.SLDPRT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]
2019-03-03 Dakje V2
    Door verkeerde maten was het dak veel te groot deze zijn aangepast en er is een verbetering toegevoegd waar nu de zijkanten eveneens ingefreest worden zoals bij de kast zelf
    [19 Bovenplaat van het deksel 19mm dikte.SLDPRT, 19 korte zijde dakje binnenkant 19mm dikte.SLDPRT, 19 korte zijde dakje buitenkant 19mm dikte.SLDPRT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]
2019-03-03 Kleine update
    Verwijderen overbodige bestanden (tmp files)
    [Dakje Assembly.SLDASM]
2019-03-04 Ontwerpronde major update
    Major update in het kader van de tweede ontwerpronde aanpassingen aan maten en toevoeging technische plannen en materiaallijsten.
    [12 balkjes 12mm dikte.SLDPRT, 12 lange binnenzijde 12mm dikte.SLDPRT, 19 Bovenplaat van het deksel 19mm dikte.SLDPRT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]
2019-03-04 Update bodemplaat assembly
    Bodemplaat (raster) update + assembly en technische plannen
    [Balkje kort voor verhoging bodemplaat met raster.SLDPRT, Balkje lang voor verhoging bodemplaat met raster.SLDPRT, Bodem met raster Assembly.SLDASM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]
2019-03-04 Ratser Toegevoegd
    Toevoeging raster in kader van ontwerpronde
    [Kast +Dak + Raster bodem Assembly.SLDASM, Kast +Dak + Raster bodem technisch plan.SLDDRW]
2019-03-04 Ontwerpronde vlieggat + toevoegen aan assembly
    In kader van ontwerpronde (vlieggat dikte + ontwerp aangepast want is 10mm dik geen 12!)
    [12 binnevlieggat 12mm dikte.SLDPRT, Kast +Dak + Raster bodem + vlieggat Assembly.SLDASM, Kast +Dak + Raster bodem + vlieggat technisch plan.SLDDRW]
2019-03-04 Ontwerpronde 2 Major update
    Ontwerpronde 2
    Major update
    Afwerken poten toevoegen luchtplaat,...
    Toevoegen materiaallijst
    [30 voetstuk bijenkast bijenkasthouder links rechts 30mm dikte (2).SLDPRT, 30 voetstuk bijenkast bijenkasthouder links rechts 30mm dikte.SLDPRT, Bijenkast Ontwe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]
2019-03-04 kleine visuele update
    [Bijenkast Tekening.SLDDRW]
2019-03-04 Ontwerpronde 2
    Major Update
    [10 extra stuk bodem onder 10mm dikte.SLDPRT, 12 binnevlieggat 12mm dikte.SLDPRT, 19 Bodemplaat met opening voor raster 19mm dikte + 12mm zijstukken.SLDPRT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]
2019-03-05 Opschonen bestanden
    Kleine update: Opschonen van de bestanden en bestandsstructuur
    [12 balkjes 12mm dikte.SLDPRT, 12 binnevlieggat 12mm dikte.SLDPRT, 12 lange binnenzijde 12mm dikte.SLDPRT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]
2019-03-09 Update materialen + bug dakje opgelost
    Update materialen + bug dakje opgelost
2019-03-16 Hardware
    toevoeging hardware
    [elektronica.fzz]
2019-03-18 pcb + rest
    [12 balkjes 12mm dikte.SLDPRT, elektronica.fzz]
2019-03-20 Update TestRun Sensor array.txt
2019-03-23 Hardware update
    [Testing board V0.8 Alt.fzz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]
2019-03-23 Update Testing board V0.8 minimal.fzz
    [Testing board V0.8 minimal.fzz]
2019-03-23 Update Testing board V0.85 minimal.fzz
    [Testing board V0.85 minimal.fzz]
